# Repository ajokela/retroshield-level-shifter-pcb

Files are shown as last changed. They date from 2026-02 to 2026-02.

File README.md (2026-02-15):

# RetroShield Level Shifter PCB — Arduino Giga R1 Shield

KiCad design files for a bidirectional 3.3V-to-5V level converter shield that sits between an [Arduino Giga R1 WiFi](https://store.arduino.cc/products/giga-r1-wifi) and a [RetroShield Z80](https://www.tindie.com/products/8bitforce/retroshield-for-arduino-mega-z80/). The shield translates all bus signals between the Giga's 3.3V logic and the RetroShield's 5V logic.

<p align="center">
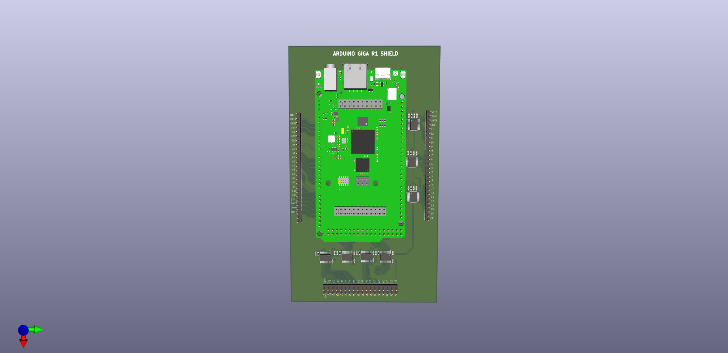
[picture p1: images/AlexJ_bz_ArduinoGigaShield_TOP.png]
3D render of the Arduino Giga R1 Level Shifter Shield — top view
  
</p>

## Design Overview

**Version:** V0.2

V0.1 used nine identical TXB0108PW auto-direction-sensing level translators. In practice, the TXB0108's direction sensing failed for several Z80 bus signals: `IORQ_N` and `RD_N` were stuck HIGH, the data bus was invisible during IO writes, and `WR_N` was unreliable during IO cycles. The firmware worked around these failures with ~1,300 lines of shadow register tracking code.

V0.2 replaces 5 of the 9 TXB0108s with purpose-matched ICs that have explicit direction control, eliminating these failures entirely:

| Position | IC | Package | Role |
|---|---|---|---|
| U1, U2, U3 | **SN74LVC541** | TSSOP-20 | Address bus + control inputs (5V→3.3V) |
| U4 | **SN74AHCT541** | TSSOP-20 | Control outputs (3.3V→5V) |
| U5 | **SN74LVC4245A** | TSSOP-24 | Data bus (bidirectional, explicit DIR) |
| U6–U9 | TXB0108PW | TSSOP-20 | Pass-through GPIO (unchanged) |

**Board specifications:**
- **Dimensions:** 155mm x 90mm (matches Arduino Giga R1 footprint)
- **Layers:** 2-layer PCB
- **Signals translated:** 72 channels covering data bus, address bus, and control signals
- **DIR pin:** Arduino D2 → U5 pin 2 (controls data bus direction)

### Signal Groups

| Signal Group | Pins | Channels | Direction | IC |
|---|---|---|---|-----|
| Address bus A0–A7 | D22–D29 | 8 | Z80 → Arduino (5V→3.3V) | U1 (74LVC541) |
| Address bus A8–A15 | D30–D37 | 8 | Z80 → Arduino (5V→3.3V) | U2 (74LVC541) |
| Control (MREQ, IORQ, RD, WR) | D39–D41, D53 | 4 | Z80 → Arduino (5V→3.3V) | U3 (74LVC541) |
| Control (CLK, RESET, INT, NMI) | D38, D50–D52 | 4 | Arduino → Z80 (3.3V→5V) | U4 (74AHCT541) |
| Data bus D0–D7 | D42–D49 | 8 | Bidirectional (DIR pin) | U5 (SN74LVC4245A) |
| Remaining GPIO | Various | 40 | Bidirectional (auto-sense) | U6–U9 (TXB0108) |

### IC Selection Rationale

- **74LVC541** (U1–U3): VCC=3.3V, inputs are 5V-tolerant. Unidirectional buffer — no direction sensing ambiguity. OE pins tied to GND (always enabled). No pull-up resistors needed.
- **74AHCT541** (U4): VCC=5V, TTL-compatible inputs accept 3.3V drive levels. Unidirectional buffer for Arduino→Z80 control signals. OE pins tied to GND.
- **SN74LVC4245A** (U5): VCCA=3.3V, VCCB=5V. Bidirectional transceiver with explicit DIR pin. DIR HIGH = A→B (Giga drives Z80 data bus), DIR LOW = B→A (Z80 drives Giga). OE tied to GND. DIR pin connected directly to Arduino D2 at 3.3V (does not go through a level shifter).
- **TXB0108PW** (U6–U9): Retained for pass-through GPIO where auto-direction sensing works fine. OE pins pulled HIGH via 10K resistors to 3.3V.

### DIR Pin

The SN74LVC4245A (U5) requires one GPIO from the Giga for direction control:

- **Arduino pin D2** (directly connected at 3.3V, no level shifter)
- **DIR HIGH** → A→B: Giga drives Z80 data bus (memory/IO writes to Z80)
- **DIR LOW** → B→A: Z80 drives Giga data bus (memory/IO reads from Z80)

This single GPIO wire replaces the entire shadow register architecture from v0.1.

## Repository Contents

```
kicad/                  KiCad 8 source files
  ├── AlexJ_bz_ArduinoGigaShield.kicad_pro    Project file
  ├── AlexJ_bz_ArduinoGigaShield.kicad_sch    Schematic
  ├── AlexJ_bz_ArduinoGigaShield.kicad_pcb    PCB layout
  └── AlexJ_bz_ArduinoGigaShield.kicad_prl    Project preferences

gerber/                 Production-ready Gerber files (v0.1 — regenerate from KiCad for v0.2)
  ├── *-F_Cu.gbr           Front copper
  ├── *-B_Cu.gbr           Back copper
  ├── *-F_Mask.gbr         Front solder mask
  ├── *-B_Mask.gbr         Back solder mask
  ├── *-F_Silkscreen.gbr   Front silkscreen
  ├── *-B_Silkscreen.gbr   Back silkscreen
  ├── *-F_Paste.gbr        Front paste (for stencil)
  ├── *-B_Paste.gbr        Back paste
  ├── *-Edge_Cuts.gbr      Board outline
  ├── *-PTH.drl            Plated through-hole drill
  ├── *-NPTH.drl           Non-plated through-hole drill
  └── *-job.gbrjob         Gerber job file

bom/                    Bill of Materials
  ├── AlexJ_bz_ArduinoGigaShield.csv     CSV format
  └── AlexJ_bz_ArduinoGigaShield.xlsx    Excel format (v0.1)

cpl/                    Component Placement
  └── AlexJ_bz_ArduinoGigaShield-all-pos.csv   Pick & place positions

schematic/              Schematic PDF (v0.1 — regenerate from KiCad for v0.2)
  └── AlexJ_bz_ArduinoGigaShield.pdf

images/                 3D renders
  ├── AlexJ_bz_ArduinoGigaShield_TOP.jpg       Top view
  ├── AlexJ_bz_ArduinoGigaShield_TOP.png       Top view (PNG)
  ├── AlexJ_bz_ArduinoGigaShield_BTM.jpg       Bottom view
  └── AlexJ_bz_ArduinoGigaShield.png           Perspective view

CHANGES-V0.2.md         Detailed design changes for KiCad implementation
```

## Bill of Materials

| Reference | Qty | Value | Part Number | Package |
|---|-----|---|---|---|
| U1, U2, U3 | 3 | SN74LVC541 | SN74LVC541PWR | TSSOP-20 |
| U4 | 1 | SN74AHCT541 | SN74AHCT541PWR | TSSOP-20 |
| U5 | 1 | SN74LVC4245A | SN74LVC4245APWR | TSSOP-24 |
| U6–U9 | 4 | TXB0108PW | TXB0108PWR | TSSOP-20 |
| C1–C18 | 18 | 0.1 uF | CC0603KRX7R9BB104 | 0603 |
| R6–R9 | 4 | 10K | RC0603FR-0710KL | 0603 |

**Cap breakdown:** U1–U3 get 1 cap each (VCC only, single supply), U4 gets 1 cap (VCC only), U5 gets 2 caps (VCCA + VCCB), U6–U9 get 3 caps each (VCCA + VCCB + extra) = 3 + 1 + 2 + 12 = 18 caps.

**Resistors:** R6–R9 are 10K pull-ups on OE pins for U6–U9 (TXB0108). R1–R5 from v0.1 are removed — the 74LVC541, 74AHCT541, and SN74LVC4245A have their OE pins tied directly to GND.

## Manufacturing

The Gerber files in `gerber/` are from v0.1. After the KiCad schematic and PCB are updated for v0.2, regenerate Gerbers before ordering.

Upload to any PCB fabrication service:

- [PCBWay](https://www.pcbway.com/)
- [JLCPCB](https://jlcpcb.com/)
- [OSH Park](https://oshpark.com/)

For SMD assembly, provide the BOM (`bom/`) and component placement file (`cpl/`) to the fab house.

### Recommended PCB Specs

| Parameter | Value |
|---|---|
| Layers | 2 |
| Board thickness | 1.6 mm |
| Copper weight | 1 oz |
| Surface finish | HASL or ENIG |
| Solder mask | Red (or your preference) |
| Silkscreen | White |

## Assembly Notes

1. **SMD components first** — solder the ICs, decoupling capacitors, and pull-up resistors
2. **Pin headers last** — solder the through-hole pin headers (female on bottom for the Giga, male on top for the RetroShield)
3. **Power jumper** — a jumper wire connects the Giga's 3.3V output to the shield's VCCA rail
4. **DIR wire** — connect Arduino D2 to U5 pin 2 (DIR) if not routed on the PCB
5. **Orientation** — check silkscreen for "V0.2" and IC labels; U5 is the wider TSSOP-24 package

## Photos

<p align="center">
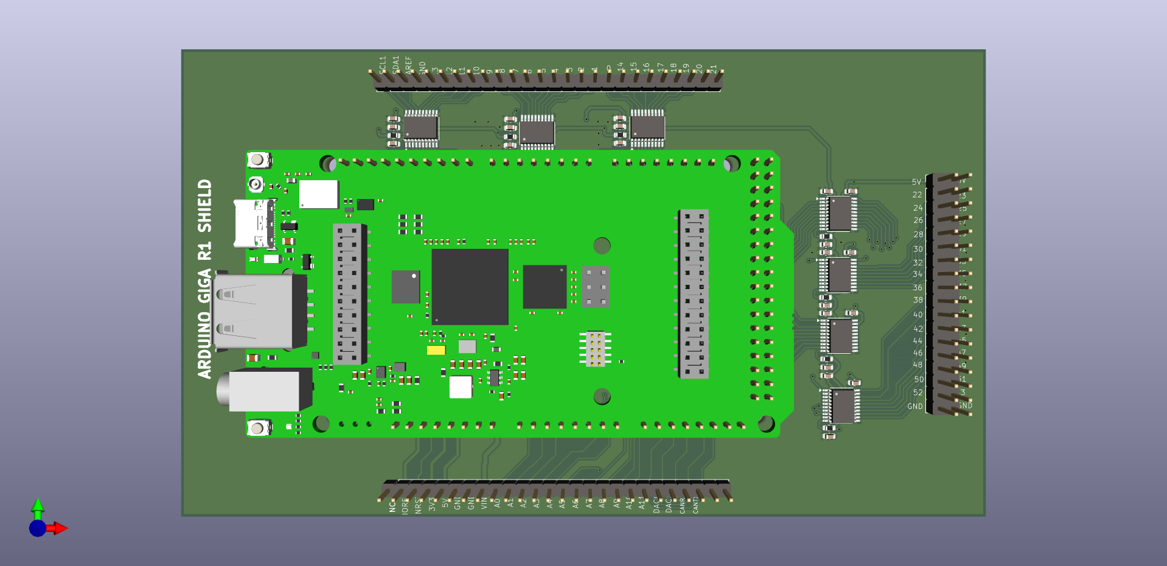
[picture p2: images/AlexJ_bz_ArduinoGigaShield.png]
3D perspective render of the shield
  
</p>

<p align="center">
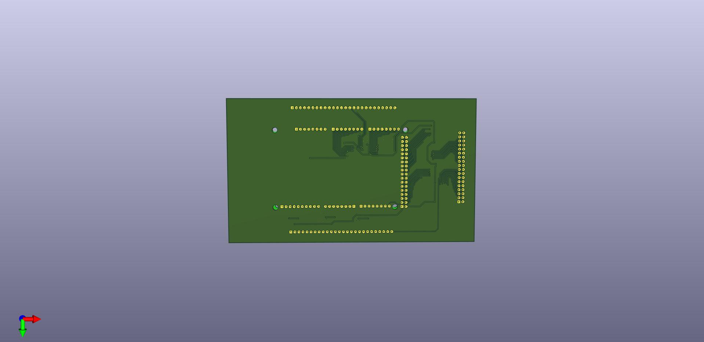
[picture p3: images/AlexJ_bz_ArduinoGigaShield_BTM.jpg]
3D render — bottom view showing routing
  
</p>

## Related Projects

- [retroshield-z80-cpm-giga](https://github.com/ajokela/retroshield-z80-cpm-giga) — Arduino Giga R1 firmware for CP/M 2.2 on the RetroShield Z80
- [retroshield-sector-server](https://github.com/ajokela/retroshield-sector-server) — Rust TCP server for WiFi-based CP/M disk I/O

## Blog Posts

This project is documented in a three-part series on [tinycomputers.io](https://tinycomputers.io):

1. [My Experience Using Fiverr for Custom PCB Design: A $468 Arduino Giga Shield](https://tinycomputers.io/posts/fiverr-pcb-design-arduino-giga-shield/)
2. [Porting CP/M to the Arduino Giga R1: When Level Converters Fight Back](https://tinycomputers.io/posts/cpm-on-arduino-giga-r1-wifi/)
3. [Playing Zork on a Real Z80: From CP/M Boot to the Great Underground Empire](https://tinycomputers.io/posts/zork-on-retroshield-z80-arduino-giga/)

## License

This work is licensed under the [Creative Commons Attribution-ShareAlike 4.0 International License](https://creativecommons.org/licenses/by-sa/4.0/) (CC BY-SA 4.0). See [LICENSE](LICENSE).

You are free to share and adapt this design, including for commercial purposes, as long as you give appropriate credit and distribute derivative works under the same license.

## Author

Alex Jokela — [tinycomputers.io](https://tinycomputers.io)

PCB design by Elijah (ekeziah) via Fiverr. Manufacturing sponsored by [PCBWay](https://www.pcbway.com/).

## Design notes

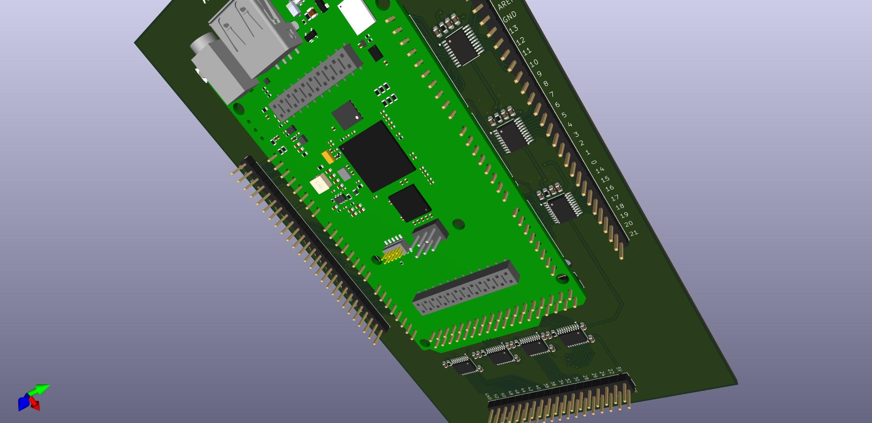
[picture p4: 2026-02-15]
images/AlexJ_bz_ArduinoGigaShield_TOP.jpg

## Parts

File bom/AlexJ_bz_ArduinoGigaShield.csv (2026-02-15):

Reference | Qty | Value | Footprint | Mfr. PART # | SUPPLIER
C1,C2,C3,C4,C5,C6,C7,C8,C9,C10,C11,C12,C13,C14,C15,C16,C17,C18 | 18 | 0.1uF | Capacitor_SMD:C_0603_1608Metric | CC0603KRX7R9BB104 | LCSC
J1,J3,J4,J6,J7 | 5 | Conn_01x08 | Connector_PinHeader_2.54mm:PinHeader_1x08_P2.54mm_Vertical | DNP | LCSC
J2 | 1 | Conn_01x10 | Connector_PinHeader_2.54mm:PinHeader_1x10_P2.54mm_Vertical | DNP | LCSC
J5,J8 | 2 | Conn_01x26 | Connector_PinHeader_2.54mm:PinHeader_1x26_P2.54mm_Vertical | DNP | LCSC
J9 | 1 | JSIDE | Connector_PinHeader_2.54mm:PinHeader_2x18_P2.54mm_Vertical | DNP | LCSC
J10 | 1 | JSIDE_5V | Connector_PinHeader_2.54mm:PinHeader_2x18_P2.54mm_Vertical | DNP | LCSC
R6,R7,R8,R9 | 4 | 10K | Resistor_SMD:R_0603_1608Metric | RC0603FR-0710KL | LCSC
U1,U2,U3 | 3 | SN74LVC541 | Package_SO:TSSOP-20_4.4x6.5mm_P0.65mm | SN74LVC541PWR | LCSC
U4 | 1 | SN74AHCT541 | Package_SO:TSSOP-20_4.4x6.5mm_P0.65mm | SN74AHCT541PWR | LCSC
U5 | 1 | SN74LVC4245A | Package_SO:TSSOP-24_4.4x7.8mm_P0.65mm | SN74LVC4245APWR | LCSC
U6,U7,U8,U9 | 4 | TXB0108PW | Package_SO:TSSOP-20_4.4x6.5mm_P0.65mm | TXB0108PWR | LCSC

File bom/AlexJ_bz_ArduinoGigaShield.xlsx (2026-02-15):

Reference | Qty | Value | Footprint | Mfr. PART # | SUPPLIER
C1,C2,C3,C4,C5,C6,C7,C8,C9,C10,C11,C12,C13,C14,C15,C16,C17,C18,C19,C20,C21,C22,C23,C24,C25,C26,C27 | 27 | 0.1uF | Capacitor_SMD:C_0603_1608Metric | CC0603KRX7R9BB104 | LCSC
J1,J3,J4,J6,J7 | 5 | Conn_01x08 | Connector_PinHeader_2.54mm:PinHeader_1x08_P2.54mm_Vertical | DNP | LCSC
J2 | 1 | Conn_01x10 | Connector_PinHeader_2.54mm:PinHeader_1x10_P2.54mm_Vertical | DNP | LCSC
J5,J8 | 2 | Conn_01x26 | Connector_PinHeader_2.54mm:PinHeader_1x26_P2.54mm_Vertical | DNP | LCSC
J9 | 1 | JSIDE | Connector_PinHeader_2.54mm:PinHeader_2x18_P2.54mm_Vertical | DNP | LCSC
J10 | 1 | JSIDE_5V | Connector_PinHeader_2.54mm:PinHeader_2x18_P2.54mm_Vertical | DNP | LCSC
R1,R2,R3,R4,R5,R6,R7,R8,R9 | 9 | 10K | Resistor_SMD:R_0603_1608Metric | RC0603FR-0710KL | LCSC
U1,U2,U3,U4,U5,U6,U7,U8,U9 | 9 | TXB0108PW | Package_SO:TSSOP-20_4.4x6.5mm_P0.65mm | TXB0108PWR | LCSC

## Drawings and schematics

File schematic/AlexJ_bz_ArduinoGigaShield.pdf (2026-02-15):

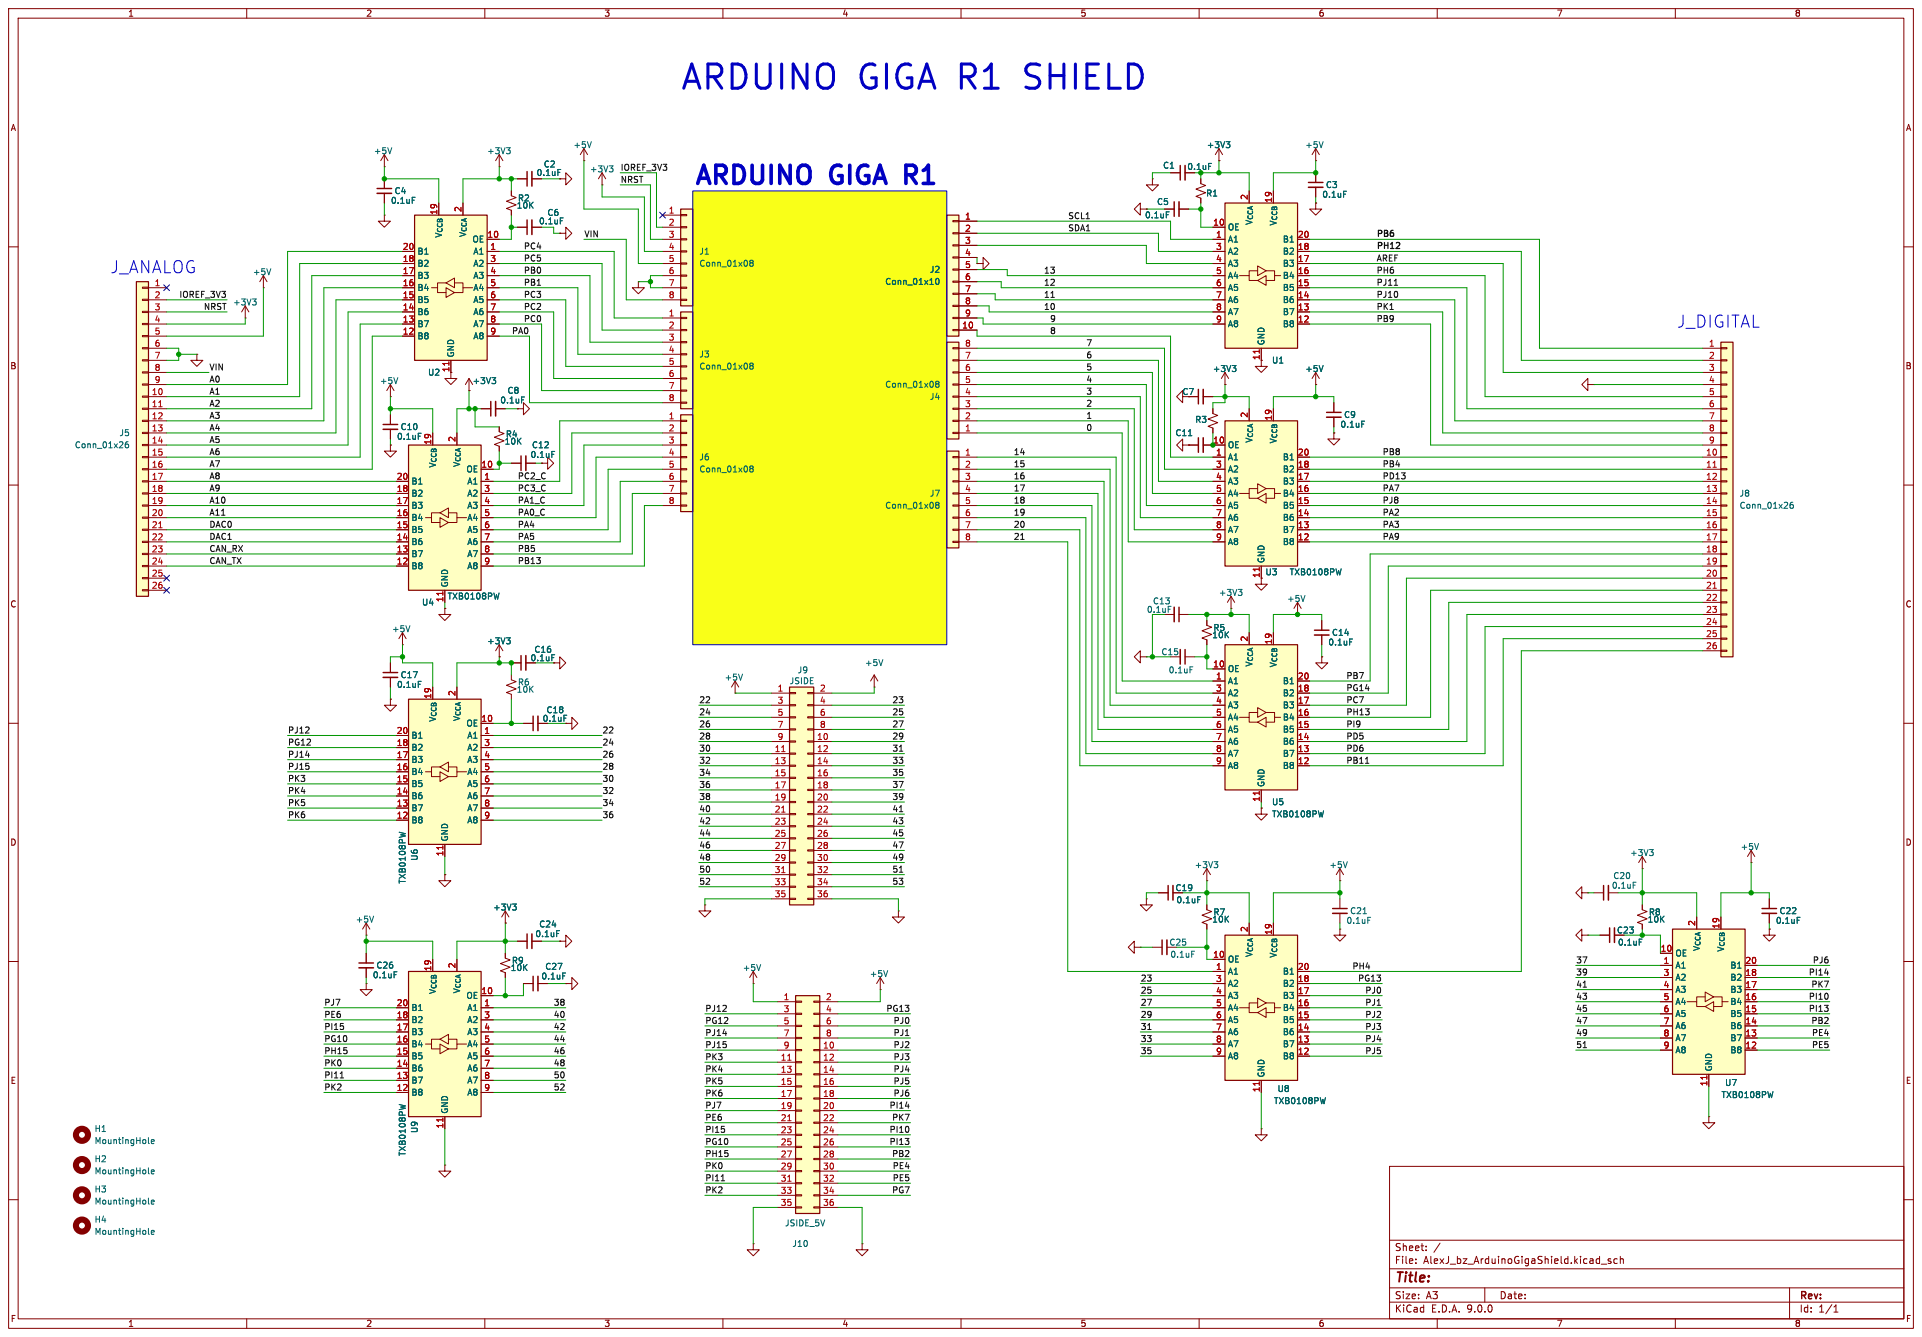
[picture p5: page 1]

OE 10 A1 1 A2 3 A3 4 A4 5 A5 6 A6 7 A7 8 A8 9 V_{CCA} 2 GND 11 V_{CCB} 19 B1 20 B2 18 B3 17 B4 16 B5 15 B6 14 B7 13 B8 12

0.1uF OE 10 A1 1 A2 3 A3 4 A4 5 A5 6 A6 7 A7 8 A8 9 V_{CCA} 2 GND 11 V_{CCB} 19 B1 20 B2 18 B3 17 B4 16 B5 15 B6 14 B7 13 B8 12 U9 TXB0108PW

0.1uF H4 MountingHole H3 MountingHole H2 MountingHole H1 MountingHole

Id: 1/1 Title: File: AlexJ_bz_ArduinoGigaShield.kicad_sch Sheet: /

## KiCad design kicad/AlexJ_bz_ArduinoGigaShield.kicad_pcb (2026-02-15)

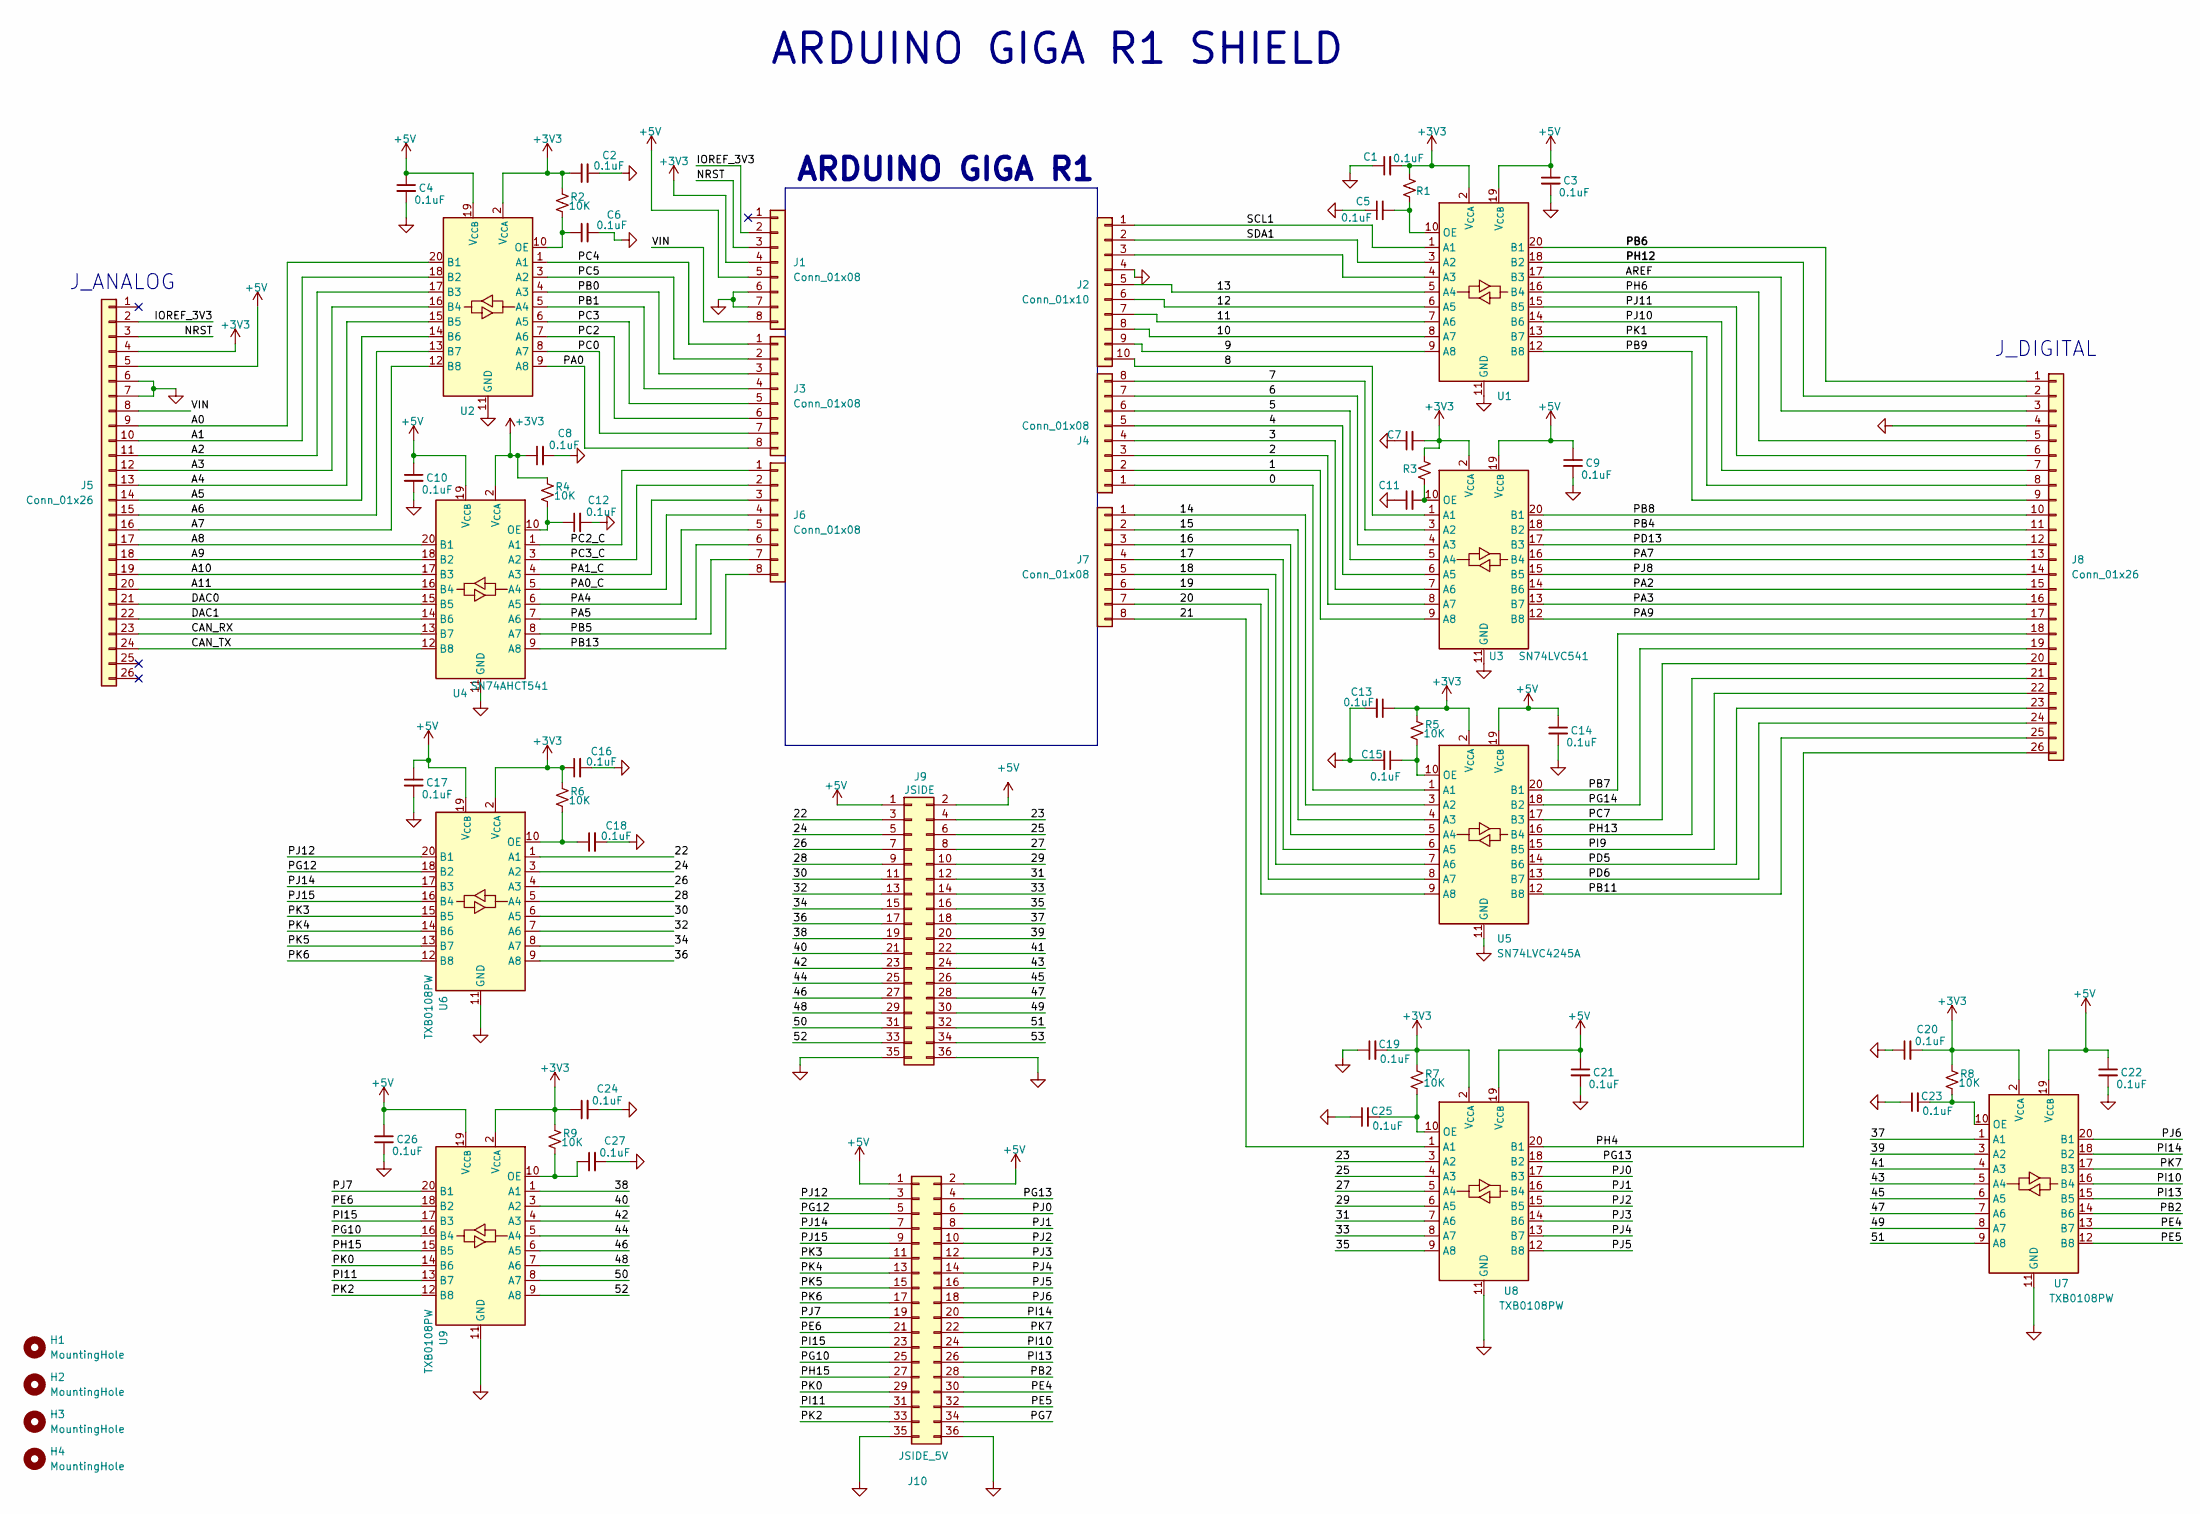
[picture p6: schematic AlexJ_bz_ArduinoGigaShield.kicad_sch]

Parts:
C1, C2, C3, C4, C5, C6, C7, C8, C9, C10, C11, C12, C13, C14, C15, C16, C17, C18, C19, C20, C21, C22, C23, C24, C25, C26, C27: 0.1uF; C_0603_1608Metric
H1, H2, H3, H4: MountingHole; MountingHole_3.2mm_M3
J1, J3, J4, J6, J7: Conn_01x08; PinHeader_1x08_P2.54mm_Vertical
J2: Conn_01x10; PinHeader_1x10_P2.54mm_Vertical
J5, J8: Conn_01x26; PinHeader_1x26_P2.54mm_Vertical
J9: JSIDE; PinHeader_2x18_P2.54mm_Vertical
J10: JSIDE_5V; PinHeader_2x18_P2.54mm_Vertical
R1, R2, R3, R4, R5, R6, R7, R8, R9: 10K; R_0603_1608Metric
U1, U2, U3: SN74LVC541; TSSOP-20_4.4x6.5mm_P0.65mm
U4: SN74AHCT541; TSSOP-20_4.4x6.5mm_P0.65mm
U5: SN74LVC4245A; TSSOP-24_4.4x7.8mm_P0.65mm
U6, U7, U8, U9: TXB0108PW; TSSOP-20_4.4x6.5mm_P0.65mm

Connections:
+3V3: C1.2, C2.1, C7.2, C8.1, C13.1, C16.1, C19.2, C20.2, C24.1, J1.4, J5.4, R1.1, R2.1, R3.1, R4.1, R5.1, R6.1, R7.1, R8.1, R9.1, U1.2 (V_{CCA}), U2.2 (V_{CCA}), U3.2 (V_{CCA}), U4.2 (V_{CCA}), U5.2 (V_{CCA}), U6.2 (V_{CCA}), U7.2 (V_{CCA}), U8.2 (V_{CCA}), U9.2 (V_{CCA})
+5V: C3.1, C4.1, C9.1, C10.1, C14.1, C17.1, C21.1, C22.1, C26.1, J1.5, J5.5, J9.1, J9.2, J10.1, J10.2, U1.19 (V_{CCB}), U2.19 (V_{CCB}), U3.19 (V_{CCB}), U4.19 (V_{CCB}), U5.19 (V_{CCB}), U6.19 (V_{CCB}), U7.19 (V_{CCB}), U8.19 (V_{CCB}), U9.19 (V_{CCB})
/0: J4.1, U5.1 (A1)
/1: J4.2, U3.9 (A8)
/2: J4.3, U3.8 (A7)
/3: J4.4, U3.7 (A6)
/4: J4.5, U3.6 (A5)
/5: J4.6, U3.5 (A4)
/6: J4.7, U3.4 (A3)
/7: J4.8, U3.3 (A2)
/8: J2.10, U3.1 (A1)
/9: J2.9, U1.9 (A8)
/10: J2.8, U1.8 (A7)
/11: J2.7, U1.7 (A6)
/12: J2.6, U1.6 (A5)
/13: J2.5, U1.5 (A4)
/14: J7.1, U5.3 (A2)
/15: J7.2, U5.4 (A3)
/16: J7.3, U5.5 (A4)
/17: J7.4, U5.6 (A5)
/18: J7.5, U5.7 (A6)
/19: J7.6, U5.8 (A7)
/20: J7.7, U5.9 (A8)
/21: J7.8, U8.1 (A1)
/22: J9.3, U6.1 (A1)
/23: J9.4, U8.3 (A2)
/24: J9.5, U6.3 (A2)
/25: J9.6, U8.4 (A3)
/26: J9.7, U6.4 (A3)
/27: J9.8, U8.5 (A4)
/28: J9.9, U6.5 (A4)
/29: J9.10, U8.6 (A5)
/30: J9.11, U6.6 (A5)
/31: J9.12, U8.7 (A6)
/32: J9.13, U6.7 (A6)
/33: J9.14, U8.8 (A7)
/34: J9.15, U6.8 (A7)
/35: J9.16, U8.9 (A8)
/36: J9.17, U6.9 (A8)
/37: J9.18, U7.1 (A1)
/38: J9.19, U9.1 (A1)
/39: J9.20, U7.3 (A2)
/40: J9.21, U9.3 (A2)
/41: J9.22, U7.4 (A3)
/42: J9.23, U9.4 (A3)
/43: J9.24, U7.5 (A4)
/44: J9.25, U9.5 (A4)
/45: J9.26, U7.6 (A5)
/46: J9.27, U9.6 (A5)
/47: J9.28, U7.7 (A6)
/48: J9.29, U9.7 (A6)
/49: J9.30, U7.8 (A7)
/50: J9.31, U9.8 (A7)
/51: J9.32, U7.9 (A8)
/52: J9.33, U9.9 (A8)
/53: J9.34
/A0: J5.9, U2.20 (B1)
/A1: J5.10, U2.18 (B2)
/A2: J5.11, U2.17 (B3)
/A3: J5.12, U2.16 (B4)
/A4: J5.13, U2.15 (B5)
/A5: J5.14, U2.14 (B6)
/A6: J5.15, U2.13 (B7)
/A7: J5.16, U2.12 (B8)
/A8: J5.17, U4.20 (B1)
/A9: J5.18, U4.18 (B2)
/A10: J5.19, U4.17 (B3)
/A11: J5.20, U4.16 (B4)
/AREF: J8.3, U1.17 (B3)
/CAN_RX: J5.23, U4.13 (B7)
/CAN_TX: J5.24, U4.12 (B8)
/DAC0: J5.21, U4.15 (B5)
/DAC1: J5.22, U4.14 (B6)
/IOREF_3V3: J1.2, J5.2
/NRST: J1.3, J5.3
/PA0: J3.8, U2.9 (A8)
/PA0_C: J6.4, U4.5 (A4)
/PA1_C: J6.3, U4.4 (A3)
/PA2: J8.15, U3.14 (B6)
/PA3: J8.16, U3.13 (B7)
/PA4: J6.5, U4.6 (A5)
/PA5: J6.6, U4.7 (A6)
/PA7: J8.13, U3.16 (B4)
/PA9: J8.17, U3.12 (B8)
/PB0: J3.3, U2.4 (A3)
/PB1: J3.4, U2.5 (A4)
/PB2: J10.28, U7.14 (B6)
/PB4: J8.11, U3.18 (B2)
/PB5: J6.7, U4.8 (A7)
/PB6: J8.1, U1.20 (B1)
/PB7: J8.18, U5.20 (B1)
/PB8: J8.10, U3.20 (B1)
/PB9: J8.9, U1.12 (B8)
/PB11: J8.25, U5.12 (B8)
/PB13: J6.8, U4.9 (A8)
/PC0: J3.7, U2.8 (A7)
/PC2: J3.6, U2.7 (A6)
/PC2_C: J6.1, U4.1 (A1)
/PC3: J3.5, U2.6 (A5)
/PC3_C: J6.2, U4.3 (A2)
/PC4: J3.1, U2.1 (A1)
/PC5: J3.2, U2.3 (A2)
/PC7: J8.20, U5.17 (B3)
/PD5: J8.23, U5.14 (B6)
/PD6: J8.24, U5.13 (B7)
/PD13: J8.12, U3.17 (B3)
/PE4: J10.30, U7.13 (B7)
/PE5: J10.32, U7.12 (B8)
/PE6: J10.21, U9.18 (B2)
/PG7: J10.34
/PG10: J10.25, U9.16 (B4)
/PG12: J10.5, U6.18 (B2)
/PG13: J10.4, U8.18 (B2)
/PG14: J8.19, U5.18 (B2)
/PH4: J8.26, U8.20 (B1)
/PH6: J8.5, U1.16 (B4)
/PH12: J8.2, U1.18 (B2)
/PH13: J8.21, U5.16 (B4)
/PH15: J10.27, U9.15 (B5)
/PI9: J8.22, U5.15 (B5)
/PI10: J10.24, U7.16 (B4)
/PI11: J10.31, U9.13 (B7)
/PI13: J10.26, U7.15 (B5)
/PI14: J10.20, U7.18 (B2)
/PI15: J10.23, U9.17 (B3)
/PJ0: J10.6, U8.17 (B3)
/PJ1: J10.8, U8.16 (B4)
/PJ2: J10.10, U8.15 (B5)
/PJ3: J10.12, U8.14 (B6)
/PJ4: J10.14, U8.13 (B7)
/PJ5: J10.16, U8.12 (B8)
/PJ6: J10.18, U7.20 (B1)
/PJ7: J10.19, U9.20 (B1)
/PJ8: J8.14, U3.15 (B5)
/PJ10: J8.7, U1.14 (B6)
/PJ11: J8.6, U1.15 (B5)
/PJ12: J10.3, U6.20 (B1)
/PJ14: J10.7, U6.17 (B3)
/PJ15: J10.9, U6.16 (B4)
/PK0: J10.29, U9.14 (B6)
/PK1: J8.8, U1.13 (B7)
/PK2: J10.33, U9.12 (B8)
/PK3: J10.11, U6.15 (B5)
/PK4: J10.13, U6.14 (B6)
/PK5: J10.15, U6.13 (B7)
/PK6: J10.17, U6.12 (B8)
/PK7: J10.22, U7.17 (B3)
/SCL1: J2.1, U1.1 (A1)
/SDA1: J2.2, U1.3 (A2)
/VIN: J1.8, J5.8
GND: C1.1, C2.2, C3.2, C4.2, C5.1, C6.2, C7.1, C8.2, C9.2, C10.2, C11.1, C12.2, C13.2, C14.2, C15.2, C16.2, C17.2, C18.2, C19.1, C20.1, C21.2, C22.2, C23.1, C24.2, C25.1, C26.2, C27.2, J1.6, J1.7, J2.4, J5.6, J5.7, J8.4, J9.35, J9.36, J10.35, J10.36, U1.11 (GND), U2.11 (GND), U3.11 (GND), U4.11 (GND), U5.11 (GND), U6.11 (GND), U7.11 (GND), U8.11 (GND), U9.11 (GND)
unnamed: J2.3, U1.4 (A3)
unnamed: C5.2, R1.2, U1.10 (OE)
unnamed: C6.1, R2.2, U2.10 (OE)
unnamed: C11.2, R3.2, U3.10 (OE)
unnamed: C12.1, R4.2, U4.10 (OE)
unnamed: C15.1, R5.2, U5.10 (OE)
unnamed: C18.1, R6.2, U6.10 (OE)
unnamed: C23.2, R8.2, U7.10 (OE)
unnamed: C25.2, R7.2, U8.10 (OE)
unnamed: C27.1, R9.2, U9.10 (OE)

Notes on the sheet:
J_ANALOG
ARDUINO GIGA R1 SHIELD
J_DIGITAL
ARDUINO GIGA R1

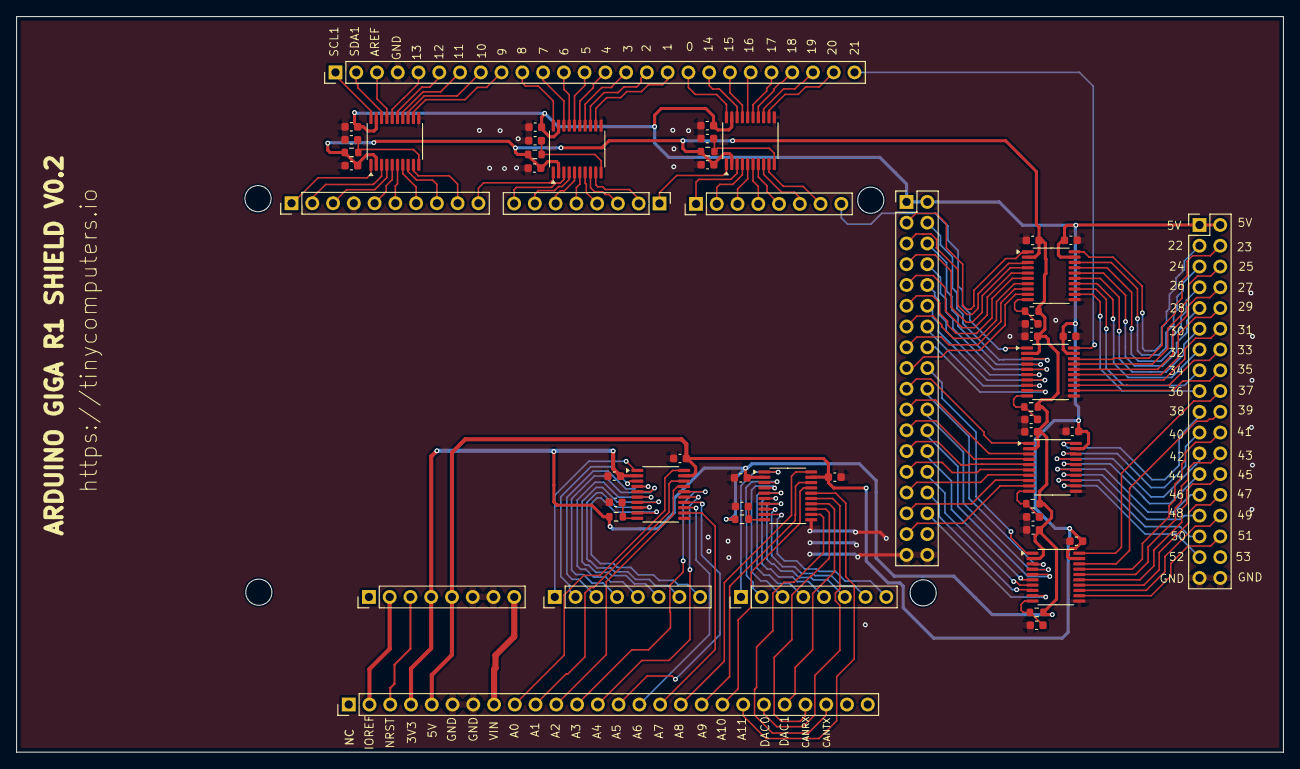
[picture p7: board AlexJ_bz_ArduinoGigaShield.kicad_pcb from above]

Board: 2 copper layers, 155.0 x 90.0 mm, 59 parts (0 on the bottom side), 159 nets.

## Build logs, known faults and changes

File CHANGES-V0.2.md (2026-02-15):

# V0.2 Design Changes — KiCad Implementation Guide

This document describes all schematic and PCB changes required to update the RetroShield Level Shifter from V0.1 to V0.2. The BOM, CPL, and README have already been updated in the repository. This file captures the KiCad-specific changes that must be done in the KiCad GUI.

## Summary

Replace 5 of 9 TXB0108PW ICs with purpose-matched level translators to eliminate auto-direction-sensing failures on the Z80 bus. Add one DIR control line from the Arduino Giga to the new bidirectional data bus transceiver.

## Schematic Changes

### U1: TXB0108PW → SN74LVC541PWR (Address A0–A7)

- **Replace symbol** with 74LVC541 (TSSOP-20, same footprint size)
- **VCC** → 3.3V (was VCCA=3.3V / VCCB=5V on TXB0108)
- **GND** → GND
- **OE1_N, OE2_N** (pins 1, 19) → tie to GND (always enabled)
- **A1–A8** (pins 2–9) → Z80 address lines A0–A7 (5V side, 5V-tolerant inputs)
- **Y1–Y8** (pins 18–11) → Arduino Giga D22–D29 (3.3V side)
- **Remove R1** (10K pull-up resistor, was on TXB0108 OE pin)
- **Remove extra decoupling cap** — only 1 cap needed (VCC), not 2 (was VCCA + VCCB)

**Pin mapping (74LVC541):**
| Pin | Function | Net |
|-----|---|-----|
| 1 | OE1_N | GND |
| 2 | A1 | ADDR_A0_5V |
| 3 | A2 | ADDR_A1_5V |
| 4 | A3 | ADDR_A2_5V |
| 5 | A4 | ADDR_A3_5V |
| 6 | A5 | ADDR_A4_5V |
| 7 | A6 | ADDR_A5_5V |
| 8 | A7 | ADDR_A6_5V |
| 9 | A8 | ADDR_A7_5V |
| 10 | GND | GND |
| 11 | Y8 | ADDR_A7_3V3 (D29) |
| 12 | Y7 | ADDR_A6_3V3 (D28) |
| 13 | Y6 | ADDR_A5_3V3 (D27) |
| 14 | Y5 | ADDR_A4_3V3 (D26) |
| 15 | Y4 | ADDR_A3_3V3 (D25) |
| 16 | Y3 | ADDR_A2_3V3 (D24) |
| 17 | Y2 | ADDR_A1_3V3 (D23) |
| 18 | Y1 | ADDR_A0_3V3 (D22) |
| 19 | OE2_N | GND |
| 20 | VCC | 3.3V |

### U2: TXB0108PW → SN74LVC541PWR (Address A8–A15)

- Same IC and wiring pattern as U1
- **A1–A8** → Z80 address lines A8–A15 (5V side)
- **Y1–Y8** → Arduino Giga D30–D37 (3.3V side)
- **Remove R2** (pull-up resistor)
- Reduce to 1 decoupling cap

### U3: TXB0108PW → SN74LVC541PWR (Control Inputs)

- Same IC as U1/U2
- **Only 4 of 8 channels used:**
  - A1 → MREQ_N_5V (pin D41)
  - A2 → IORQ_N_5V (pin D39)
  - A3 → RD_N_5V (pin D53)
  - A4 → WR_N_5V (pin D40)
  - A5–A8 → **tie to GND** (unused inputs must not float)
- **Y1–Y4** → corresponding 3.3V Arduino pins
- **Y5–Y8** → leave unconnected (outputs of unused channels)
- **Remove R3** (pull-up resistor)
- Reduce to 1 decoupling cap

### U4: TXB0108PW → SN74AHCT541PWR (Control Outputs)

- **Replace symbol** with 74AHCT541 (TSSOP-20, same footprint size)
- **VCC** → **5V** (not 3.3V — this drives 5V outputs)
- **OE1_N, OE2_N** → tie to GND
- **A1–A4** → Arduino 3.3V outputs (TTL-compatible inputs accept 3.3V HIGH):
  - A1 → CLK_3V3 (D38)
  - A2 → RESET_N_3V3 (D50)
  - A3 → INT_N_3V3 (D51)
  - A4 → NMI_N_3V3 (D52)
  - A5–A8 → **tie to GND** (unused inputs)
- **Y1–Y4** → Z80 control signals at 5V
- **Y5–Y8** → leave unconnected
- **Remove R4** (pull-up resistor)
- Reduce to 1 decoupling cap (VCC = 5V)

### U5: TXB0108PW → SN74LVC4245APWR (Data Bus)

- **Replace symbol** with SN74LVC4245A
- **Change footprint** from TSSOP-20 to **TSSOP-24** (4.4x7.8mm, 0.65mm pitch)
- **VCCA** (pin 1) → 3.3V
- **VCCB** (pin 24) → 5V
- **DIR** (pin 2) → new net "DATA_DIR" from Arduino D2 header pin
- **OE_N** (pin 23) → GND (always enabled)
- **A1–A8** (pins 3–6, 8–11) → Arduino data bus D42–D49 (3.3V side)
- **B1–B8** (pins 21–18, 16–13) → Z80 data bus D0–D7 (5V side)
- **GND** (pin 12) → GND
- **Remove R5** (pull-up resistor)
- **2 decoupling caps** needed (VCCA + VCCB)

**Pin mapping (SN74LVC4245A, TSSOP-24):**
| Pin | Function | Net |
|-----|---|-----|
| 1 | VCCA | 3.3V |
| 2 | DIR | DATA_DIR (Arduino D2) |
| 3 | A1 | DATA_D0_3V3 (D42) |
| 4 | A2 | DATA_D1_3V3 (D43) |
| 5 | A3 | DATA_D2_3V3 (D44) |
| 6 | A4 | DATA_D3_3V3 (D45) |
| 7 | GND (note: pin 7 is GND on '4245A) | GND |
| 8 | A5 | DATA_D4_3V3 (D46) |
| 9 | A6 | DATA_D5_3V3 (D47) |
| 10 | A7 | DATA_D6_3V3 (D48) |
| 11 | A8 | DATA_D7_3V3 (D49) |
| 12 | GND | GND |
| 13 | B8 | DATA_D7_5V |
| 14 | B7 | DATA_D6_5V |
| 15 | B6 | DATA_D5_5V |
| 16 | B5 | DATA_D4_5V |
| 17 | GND (note: pin 17 is GND on '4245A) | GND |
| 18 | B4 | DATA_D3_5V |
| 19 | B3 | DATA_D2_5V |
| 20 | B2 | DATA_D1_5V |
| 21 | B1 | DATA_D0_5V |
| 22 | GND | GND |
| 23 | OE_N | GND |
| 24 | VCCB | 5V |

**Important:** Verify the exact pinout against the [SN74LVC4245A datasheet](https://www.ti.com/lit/ds/symlink/sn74lvc4245a.pdf) before routing. The pin mapping above is based on the TI datasheet but should be confirmed for the specific PWR (TSSOP-24) package variant.

### U6–U9: TXB0108PW (Unchanged)

- No changes to these ICs
- Keep R6–R9 (10K pull-ups on OE pins)
- Keep 3 decoupling caps each (VCCA + VCCB + extra)

### DIR Net (New)

- Add new net "DATA_DIR" from the Arduino Giga header pin D2 to U5 pin 2
- This is a direct 3.3V connection — does **not** go through any level shifter
- D2 must be routed from whichever header connector carries that pin to U5

### Removed Components

| Component | Was | Reason |
|---|-----|---|
| R1 | 10K OE pull-up for U1 | OE tied to GND instead |
| R2 | 10K OE pull-up for U2 | OE tied to GND instead |
| R3 | 10K OE pull-up for U3 | OE tied to GND instead |
| R4 | 10K OE pull-up for U4 | OE tied to GND instead |
| R5 | 10K OE pull-up for U5 | OE tied to GND instead |
| C19–C27 | Decoupling caps | Reduced cap count (single-supply ICs need fewer caps) |

### Decoupling Cap Assignments

| IC | Caps | Rail(s) |
|----|---|---|
| U1 (74LVC541) | C1 | VCC (3.3V) |
| U2 (74LVC541) | C2 | VCC (3.3V) |
| U3 (74LVC541) | C3 | VCC (3.3V) |
| U4 (74AHCT541) | C4 | VCC (5V) |
| U5 (SN74LVC4245A) | C5, C6 | VCCA (3.3V), VCCB (5V) |
| U6 (TXB0108) | C7, C8, C9 | VCCA (3.3V), VCCB (5V), extra |
| U7 (TXB0108) | C10, C11, C12 | VCCA (3.3V), VCCB (5V), extra |
| U8 (TXB0108) | C13, C14, C15 | VCCA (3.3V), VCCB (5V), extra |
| U9 (TXB0108) | C16, C17, C18 | VCCA (3.3V), VCCB (5V), extra |

## PCB Layout Changes

### Footprint Changes

- **U5**: Change from TSSOP-20 (4.4x6.5mm) to **TSSOP-24 (4.4x7.8mm)**
  - Same 0.65mm pitch, +1.3mm body length, 4 extra pins
  - U5 position may need slight adjustment to clear neighboring components
  - The wider body extends equally in both directions from center

### Trace Rerouting

- **U1–U3**: The 74LVC541 has a different pinout from TXB0108 (A/Y instead of A/B). All signal traces to U1–U3 need rerouting to match the new pin assignments.
- **U4**: Same pinout rerouting needed for 74AHCT541.
- **U5**: Complete reroute needed — different IC, different pinout, different footprint, plus new DIR trace.
- **DIR trace**: New trace from header pin (D2) to U5 pin 2. Route on whichever layer has space.
- **OE pins**: U1–U5 OE pins route to GND instead of pull-up resistors. Shorter traces.
- **Power traces**: U4 VCC changes from 3.3V to 5V. Ensure adequate trace width for the 5V power connection.

### Silkscreen Updates

- Change board label from "V0.1" to **"V0.2"**
- Update IC reference labels: U1–U3 = "74LVC541", U4 = "74AHCT541", U5 = "LVC4245A"
- Add "DIR" label near U5 pin 2 and the header connection
- Remove silkscreen for R1–R5 and C19–C27

### Design Rule Check

After all changes, run DRC to verify:
- No unconnected nets
- No clearance violations (especially around U5's wider footprint)
- All power nets correctly assigned
- DIR net connectivity from header to U5

## Schematic Changes Completed (Text Edits)

The following schematic changes have been applied directly to the `.kicad_sch` file:

- U1–U5 lib_symbols replaced (SN74LVC541, SN74AHCT541, SN74LVC4245A)
- U1–U5 lib_id, Value, Datasheet, Description properties updated
- New lib_symbol definitions added with pin positions matching TXB0108PW layout
- R1–R5 pull-up resistors removed (symbols, +3V3 power symbols, wires, junctions)
- C19–C27 extra decoupling caps removed (symbols, GND power symbols, wires)
- GND symbols added at 1OE and 2OE pin positions for U1–U4
- GND symbol added at U5 OE_N (pin 23, new bottom pin)
- +5V symbols replaced with GND at VCCB/2OE positions for U1–U3
- +5V power symbol added at U4 VCC (was +3V3, AHCT541 needs 5V)
- +3V3 power symbols restored at U1–U3, U5 VCC/VCCA positions
- DATA_DIR net label added at U5 DIR pin and on Arduino D2 wire
- Hidden GND pins 7, 17, 22 added to SN74LVC4245A lib_symbol
- Silkscreen text changed from V0.1 to V0.2

## Remaining KiCad GUI Work

The following changes require the KiCad schematic editor:

1. **U3/U4 unused channel rewiring**: Channels 5–8 on U3 and U4 currently have GPIO signals (PJ8, PA2, PA3, PA9, PA4, PA5, PB5, PB13) connected from v0.1. These bidirectional signals must be moved to U6–U9 (TXB0108PW), then A5–A8 inputs tied to GND and Y5–Y8 outputs marked no-connect.
2. **PCB footprint change**: U5 footprint geometry must be changed from TSSOP-20 to TSSOP-24 (pad positions, courtyard, silkscreen).
3. **PCB trace rerouting**: All signal traces to U1–U5 need rerouting for new IC pinouts. DIR trace from D2 header to U5.
4. **PCB component removal**: Remove R1–R5 and C19–C27 footprints/pads from PCB layout.
5. **PCB silkscreen**: Update IC reference labels, add DIR label.
6. **DRC**: Run Design Rule Check after all changes.

## Gerber Regeneration

After completing all KiCad changes:
1. Run DRC and fix any errors
2. Export new Gerber files to `gerber/`
3. Export new drill files
4. Export updated schematic PDF to `schematic/`
5. Update component placement export to `cpl/`
6. Verify BOM matches schematic

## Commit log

2026-02-15 Initial release: KiCad design files for Arduino Giga R1 level converter shield
    [AlexJ_bz_ArduinoGigaShield-B_Cu.gbr, AlexJ_bz_ArduinoGigaShield-B_Mask.gbr, AlexJ_bz_ArduinoGigaShield-B_Paste.gbr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]
2026-02-15 v0.2 design: replace 5x TXB0108 with purpose-matched level translators
    Replace U1-U3 with SN74LVC541 (address bus, control inputs),
    U4 with SN74AHCT541 (control outputs), and U5 with SN74LVC4245A
    (data bus with explicit DIR pin). Eliminates TXB0108 auto-direction
    sensing failures on IORQ_N, RD_N, and data bus during IO writes.
    Updated BOM, CPL, README, and added CHANGES-V0.2.md with detailed
    KiCad schematic/PCB implementation guide for the designer.
    [AlexJ_bz_ArduinoGigaShield.csv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]
2026-02-15 Update KiCad schematic and PCB annotations for v0.2 IC replacements
    Schematic: Update Value, Datasheet, and Description properties on U1-U5
    to reflect new IC types (SN74LVC541, SN74AHCT541, SN74LVC4245A).
    Update U5 Footprint property to TSSOP-24.
    PCB: Update Value, Datasheet, and Description on U1-U5 footprints.
    Update U5 footprint reference to TSSOP-24. Change silkscreen from
    V0.1 to V0.2.
    Note: lib_symbol definitions, pin mappings, footprint geometry, and
    trace routing still reference TXB0108PW and must be updated in
    KiCad GUI. See CHANGES-V0.2.md for full implementation guide.
    [AlexJ_bz_ArduinoGigaShield.kicad_pcb, AlexJ_bz_ArduinoGigaShield.kicad_sch]
2026-02-15 v0.2 schematic: replace U1-U5 with purpose-matched level translators
    - Replace U1-U3 lib_symbols from TXB0108PW to SN74LVC541 (address bus + control inputs)
    - Replace U4 lib_symbol to SN74AHCT541 (control outputs)
    - Replace U5 lib_symbol to SN74LVC4245A (bidirectional data bus with DIR)
    - Add lib_symbol definitions for SN74LVC541, SN74AHCT541, SN74LVC4245A
    - Remove R1-R5 pull-up resistors (OE pins now tied to GND)
    - Add GND symbols at 1OE and 2OE pins for U1-U4
    - Add GND at U5 OE_N pin (new bottom pin on TSSOP-24)
    - Add DATA_DIR net label at U5 DIR pin for Arduino D2 connection
    - Change U4 VCC from +3V3 to +5V (AHCT541 runs on 5V rail)
    - Replace +5V with GND at VCCB/2OE positions for U1-U3
    -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
    [AlexJ_bz_ArduinoGigaShield.kicad_sch]
2026-02-15 Remove C19-C27 extra decoupling caps from schematic
    The v0.1 design had 27 caps (3 per TXB0108). With v0.2's single-supply
    ICs (U1-U4), only 1 cap per IC is needed. U5 keeps 2 (VCCA+VCCB).
    U6-U9 keep 3 each. Total: 18 caps (C1-C18).
    Also removes 7 dedicated GND symbols and connecting wires.
    [AlexJ_bz_ArduinoGigaShield.kicad_sch]
2026-02-15 Add DATA_DIR net, U5 hidden GND pins, and update change log
    - Add DATA_DIR label at U5 DIR pin (262.89, 148.59)
    - Add DATA_DIR label on Arduino D2 wire (225.0, 93.98) to connect nets
    - Add hidden GND pins 7, 17, 22 to SN74LVC4245A lib_symbol
    - Update CHANGES-V0.2.md with completed schematic edits and remaining GUI work
    [AlexJ_bz_ArduinoGigaShield.kicad_sch]
